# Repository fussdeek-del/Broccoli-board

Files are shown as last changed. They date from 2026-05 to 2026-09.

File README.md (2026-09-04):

# Broccoli Board


[]()
[]()
[]()
[]()
[]()

> A fully wireless 75% mechanical keyboard built from scratch custom PCB, per-key RGB, BLE 5.0, hot-swap switches, and a 3D printed case. Every component chosen, every trace routed by hand.

---

## What is it?

Broccoli Board is a custom 84-key 75% keyboard I designed completely from scratch. The PCB is designed in KiCad, the case in Fusion 360, and the firmware runs on ZMK. It's fully wireless over BLE 5.0 via the nice!nano V2, has per-key RGB LEDs reverse-mounted on the back of the PCB, and uses Kailh hot-swap sockets so I can swap switches without touching a soldering iron.

## Why i built it?
I didn't want to spend $200+ on a keyboard that still isn't fully mine. So I built one my own that belong to me.

---

## Zine

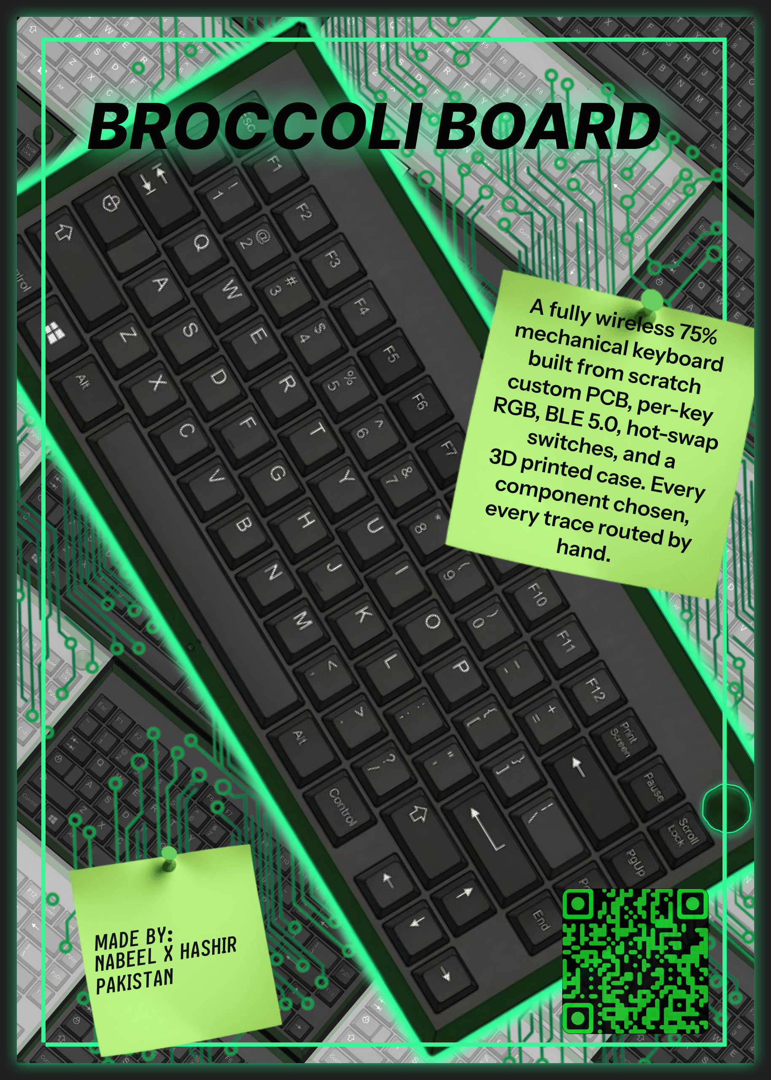
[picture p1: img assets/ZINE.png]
Zine


---

## Gallery

### CAD & Assembly
<table>
  <tr>
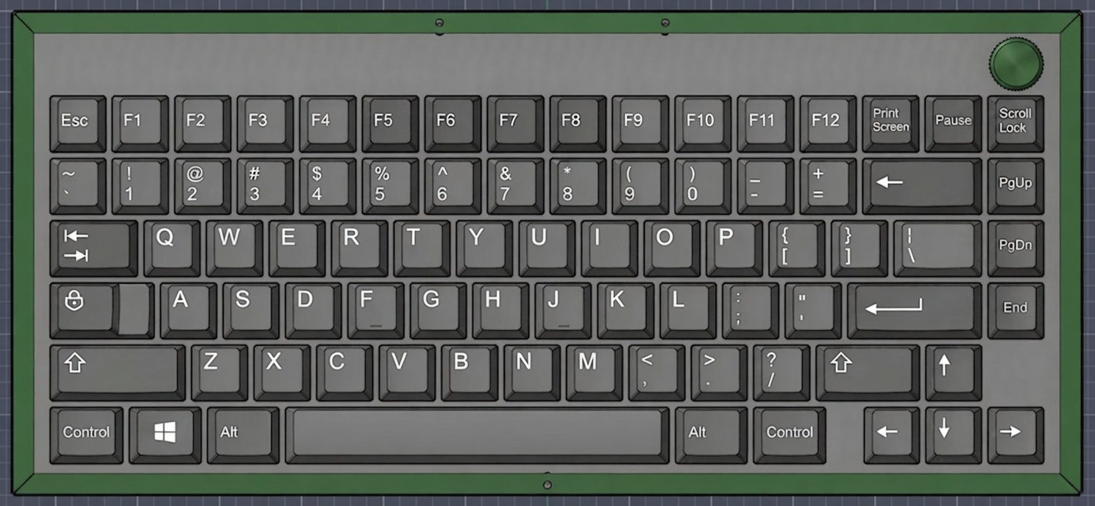
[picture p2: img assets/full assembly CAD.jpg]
    <td></td>
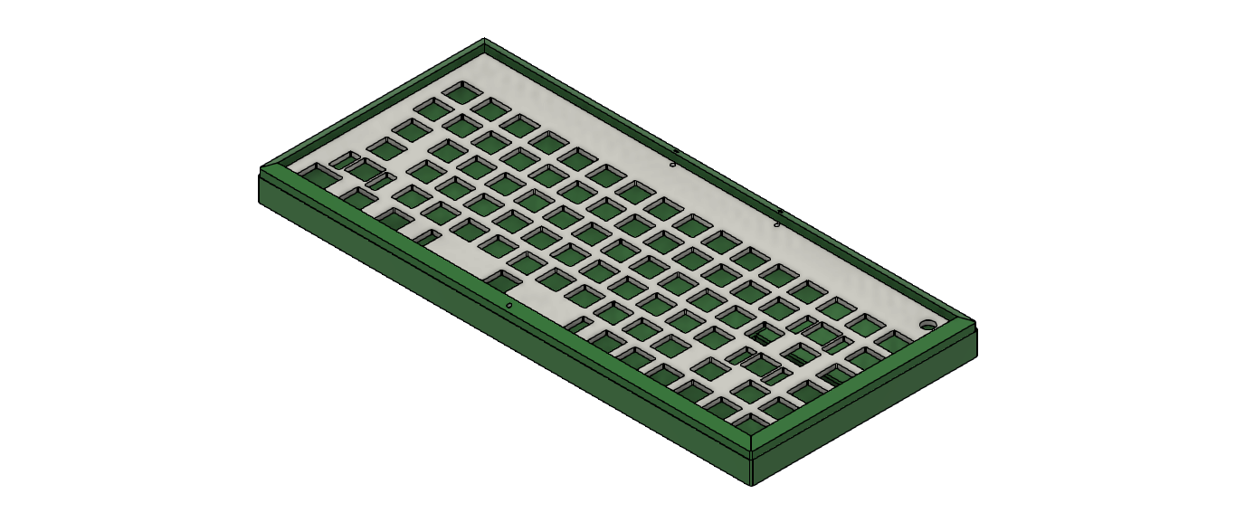
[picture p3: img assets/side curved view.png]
    <td></td>
  </tr>
</table>

### PCB
<table>
  <tr>
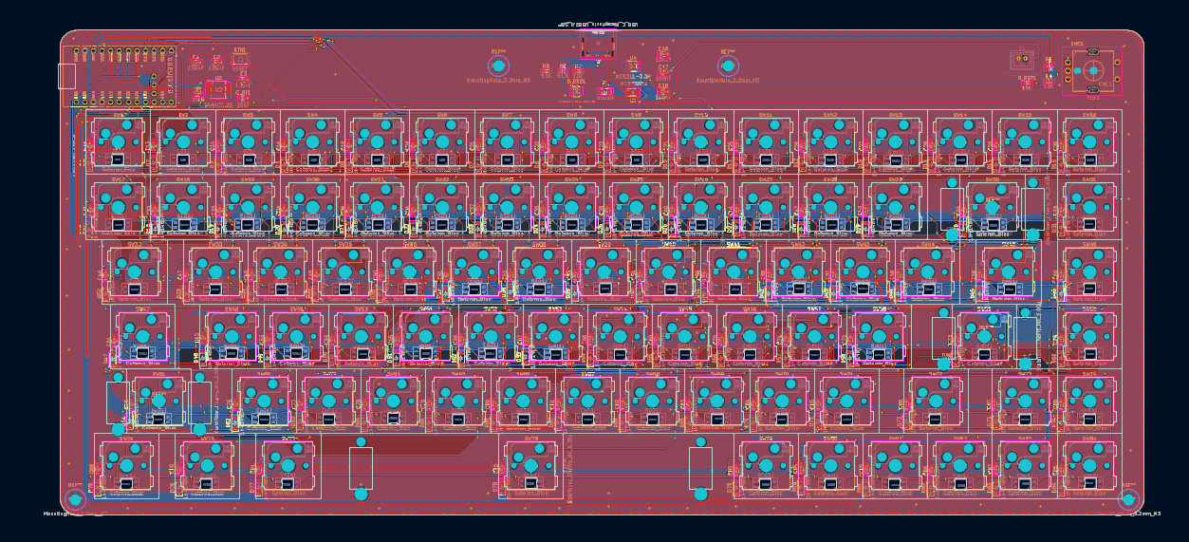
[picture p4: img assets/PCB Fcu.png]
    <td></td>
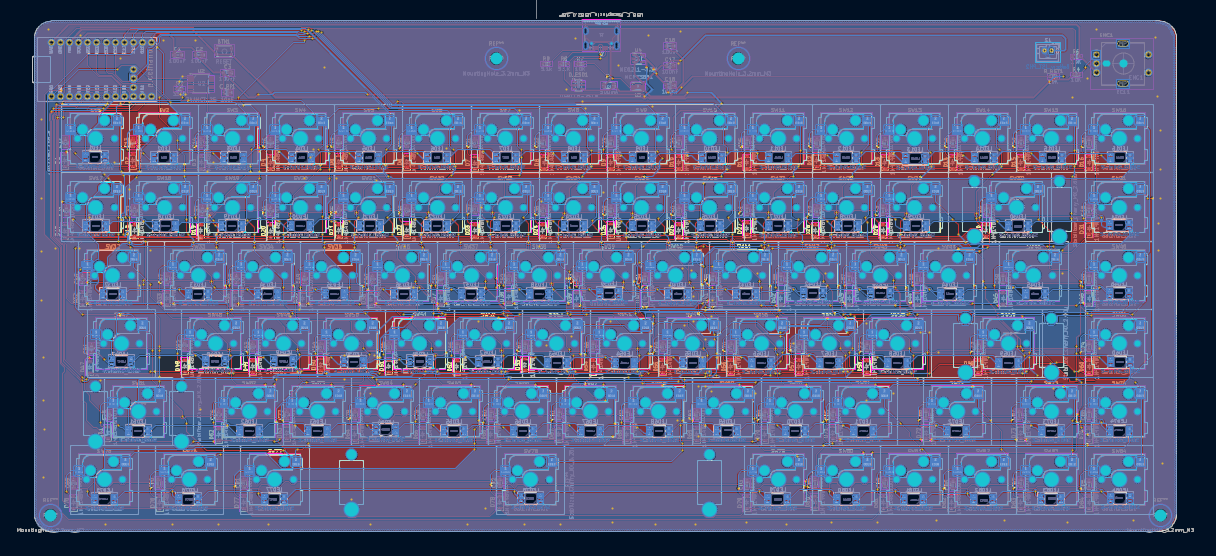
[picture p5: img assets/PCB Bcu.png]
    <td></td>
  </tr>
</table>
---

### PCB Soldered

## Features

- 84 keys, 75% layout
- Wireless BLE 5.0 via nice!nano V2 (nRF52840)
- Per-key SK6812 Mini-E RGB reverse mount on B.Cu
- Kailh hot-swap sockets no soldering to swap switches
- Rotary encoder with push switch (EC11)
- USB-C wired + wireless dual mode
- 3.7V LiPo 2000mAh with MCP73831 charger IC
- 74AHCT125 level shifter for LED data
- USBLC6-2SC6 ESD protection on USB lines
- ZMK firmware
- 2-layer PCB, KiCad 10, JLCPCB fabrication
- Custom 3D printed case tray, plate, and bezel

---

## Hardware Specs

| Component | Details |
|---|---|
| MCU | nice!nano V2 (nRF52840), socketed |
| Layout | 75%, 84 keys |
| Switches | Gateron Blue × 84, 5-pin PCB mount |
| Hotswap | Kailh CPG151101S11 × 84 |
| LEDs | SK6812 Mini-E × 84, reverse mount |
| Encoder | EC11 rotary encoder with push switch |
| Wireless | Bluetooth 5.0 BLE |
| Firmware | ZMK |
| Battery | 3.7V LiPo 2000mAh (804050), JST PH2 |
| Charger IC | MCP73831, 500mA |
| Regulator | ME6211 3.3V LDO |
| Level shifter | 74AHCT125 |
| ESD protection | USBLC6-2SC6 |
| USB connector | GCT USB4105, 16-pin USB-C |
| PCB | 2-layer, JLCPCB, KiCad 10 |
| Case | SLA resin 3D print, Fusion 360 |
| Matrix | 9 rows × 10 columns, col2row |

---

## How to Build

### Order the PCB
1. Go to [JLCPCB](https://jlcpcb.com)
2. Upload `pcb/gerbers.zip`
3. 2-layer, FR-4, 1.6mm, HASL or ENIG
4. Minimum order 5 boards

### Flash the Firmware
1. Fork the [ZMK firmware repo](https://github.com/fussdeek-del/Broccoli--board-zmk)
2. Edit keymap at `boards/shields/broccoli_board/broccoli_board.keymap`
3. Push GitHub Actions builds automatically
4. Download `.uf2` from Actions artifacts
5. Double-tap reset on nice!nano to enter bootloader
6. Drag `.uf2` onto the USB drive that appears

note: The frimware isn't completely, i will complete it once this gets approved.

### Assembly Notes
- Solder LEDs on **B.Cu** reverse mount facing down
- Solder hotswap sockets on **F.Cu**
- Solder the nice!nano v2
- Battery connects via JST PH2 to J2

## BOM

> 💰 Estimated total: **~$174 USD** — can drop to **$120–$140** buying locally.

| Component | Spec | Qty | Price | Notes | Link |
|---|---|---|---|---|---|
| Microcontroller (MCU) | nice!nano V2 nRF52840 | ×1 | $7.00 | Clone — cheaper, slightly less reliable | [Buy](https://www.aliexpress.com/item/1005006271881076.html) |
| 74AHCT125 Level Shifter | TSSOP-14 | ×1 | $2.52 | Pack of 10 — LED data 3.3V→5V | [Buy](https://www.aliexpress.com/item/1005008171122183.html) |
| MCP73831 LiPo Charger | SOT-23-5 | ×1 | $2.50 | Pack of 10 — LiPo charging IC | [Buy](https://www.aliexpress.com/item/1005007439657191.html) |
| ME6211 3.3V LDO | ME6211C33 SOT-23-5 | ×1 | $2.20 | Pack of 10 — 3.3V regulator | [Buy](https://www.aliexpress.com/item/1005007315116858.html) |
| USBLC6-2SC6 ESD Protection | SOT-23-6 | ×1 | $1.50 | Pack of 10 — USB ESD protection | [Buy](https://www.aliexpress.com/item/32807108222.html) |
| Gateron Blue Switch | G Pro Blue 5-pin | ×84 | $24.00 | Pack of 100 — 5-pin PCB mount | [Buy](https://www.aliexpress.com/item/1005006091988869.html) |
| Kailh Hotswap Socket | MX compatible | ×84 | $7.00 | Pack of 100 | [Buy](https://www.aliexpress.com/item/1005006105603269.html) |
| EC11 Rotary Encoder | 20mm with push switch | ×1 | $2.00 | Pack of 5 | [Buy](https://www.aliexpress.com/item/1005006460161288.html) |
| Reset Button | SMD tactile 3×4mm | ×1 | $1.50 | Pack of 30 | [Buy](https://www.aliexpress.com/item/4001107416458.html) |
| SK6812 Mini-E RGB LED | Reverse mount | ×84 | $13.50 | Pack of 100 — buy 100, need 84 + spares | [Buy](https://www.aliexpress.com/item/1005004249903121.html) |
| 1N4148W Matrix Diode | SOD-123 | ×84 | $1.50 | Pack of 100 — buy 100, need 84 + spares | [Buy](https://www.aliexpress.com/item/1005010728396328.html) |
| Resistor 10K | 0603 | ×10 | $1.20 | Pack of 300 | [Buy](https://www.aliexpress.com/item/1005011779883974.html) |
| Resistor 5.1K | 0603 | ×5 | $1.30 | Pack of 300 | [Buy](https://www.aliexpress.com/item/1005011779883974.html) |
| Resistor 330Ω | 0603 | ×1 | $2.00 | Pack of 500 | [Buy](https://www.aliexpress.com/item/1005005700395390.html) |
| Capacitor 100nF | 0805 | ×100 | $2.00 | Pack of 200 | [Buy](https://www.aliexpress.com/item/1005007660078779.html) |
| Capacitor 10µF | 0805 | ×1 | $2.20 | Pack of 200 | [Buy](https://www.aliexpress.com/item/1005007660078779.html) |
| USB-C Receptacle 16P | GCT USB4105 SMD | ×1 | $4.50 | Pack of 5 | [Buy](https://www.aliexpress.com/item/1005005581945089.html) |
| JST PH2 2-pin | PH2.0 2-pin connector | ×1 | $2.00 | Pack of 2 | [Buy](https://www.aliexpress.com/item/1005010615395743.html) |
| Polyfuse 500mA | Resettable fuse 1206 | ×1 | $1.70 | Pack of 10 | [Buy](https://www.aliexpress.com/item/1005005235906949.html) |
| LiPo 3.7V 2000mAh | 804050, JST PH | ×1 | $9.40 | Price for 2 | [Buy](https://www.aliexpress.com/item/1005005984841109.html) |
| Keycap Set | PBT 75% MX compatible | ×75 | $22.50 | 100+ keycaps included | [Buy](https://www.aliexpress.com/item/1005007416863215.html) |
| Rotary Knob | Aluminum 6mm D shaft 20mm | ×1 | $2.00 | 2 pieces | [Buy](https://www.aliexpress.com/item/4001091267351.html) |
| PCB Fabrication | 2-layer, FR-4, 1.6mm, HASL | ×5 boards | $22.20 | Minimum 5 pieces | [JLCPCB](https://cart.jlcpcb.com/quote) |
| 3D Print — Tray | SLA resin | ×1 | $25.30 | Local 3D printer recommended | [JLC3DP](https://jlc3dp.com/3d-printing-quote) |
| 3D Print — Top Plate | SLA resin | ×1 | $8.30 | Local 3D printer recommended | [JLC3DP](https://jlc3dp.com/3d-printing-quote) |
| 3D Print — Top Cover | SLA resin | ×1 | $2.65 | Local 3D printer recommended | [JLC3DP](https://jlc3dp.com/3d-printing-quote) |
| M3 Screws | M3 × 8mm countersunk | ×10 | $1.00 | Pack of 50 | [Buy](https://www.aliexpress.com/item/1005008810897680.html) |
| M3 Standoffs | M3 × 4mm | ×10 | $1.00 | Pack of 50 | [Buy](https://www.aliexpress.com/item/1005008810897680.html) |

---
## Schematics note
Schematics is reviewed my multiple people in fallout + AI. there was problem init that i fixed, and now it LGTM
repo is surface checked by riitam
## Credits

- [KiCad](https://www.kicad.org/) — PCB design
- [ZMK Firmware](https://zmk.dev/) — open source keyboard firmware
- [Fusion 360](https://www.autodesk.com/products/fusion-360/) — case design
- [nice!nano](https://nicekeyboards.com/nice-nano/) — nRF52840 BLE module
- [Hack Club Fallout](https://fallout.hackclub.com) — grant that made this real

Made by **Nabeel Ahmed (18) × Hashir (17)** — Punjab, Pakistan 🇵🇰 BWP

---

## License

MIT

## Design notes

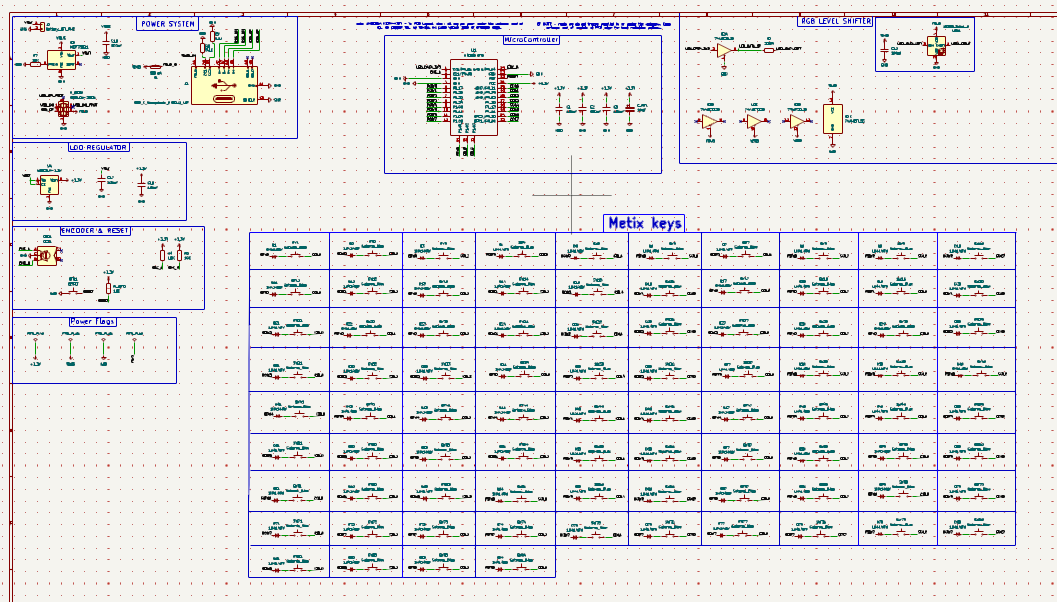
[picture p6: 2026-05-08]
img assets/schematic page1.png

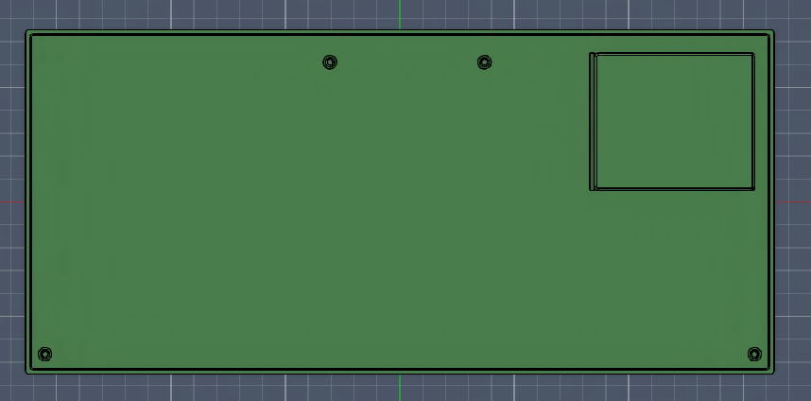
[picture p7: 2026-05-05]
img assets/Tray front.png

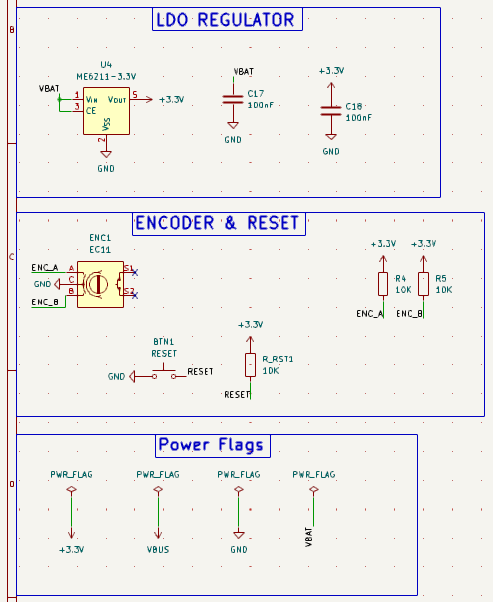
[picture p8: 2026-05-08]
img assets/small coms sch.png

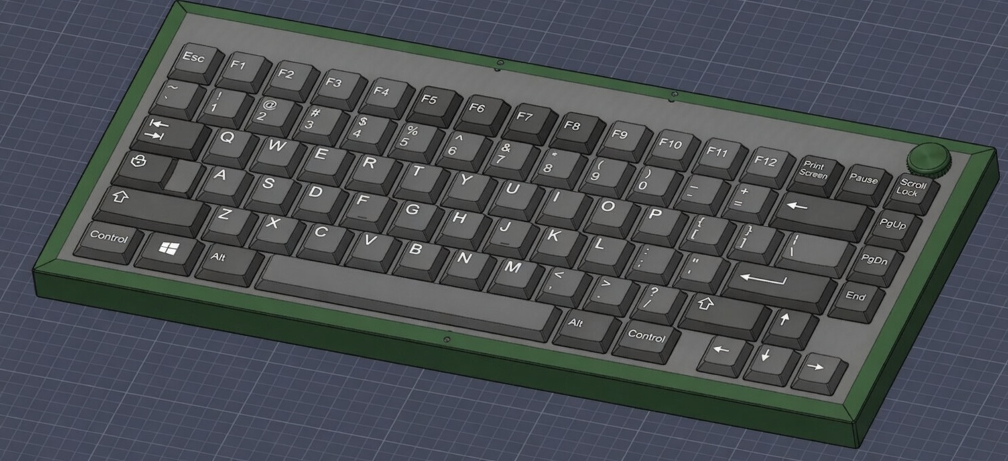
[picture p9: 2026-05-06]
img assets/CAD side look 2.jpg

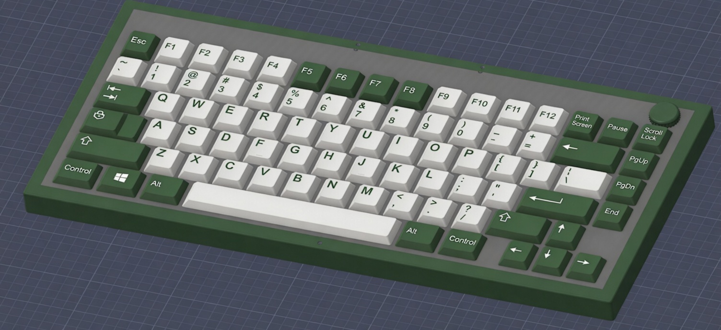
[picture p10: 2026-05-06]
img assets/AI generated final look.jpg

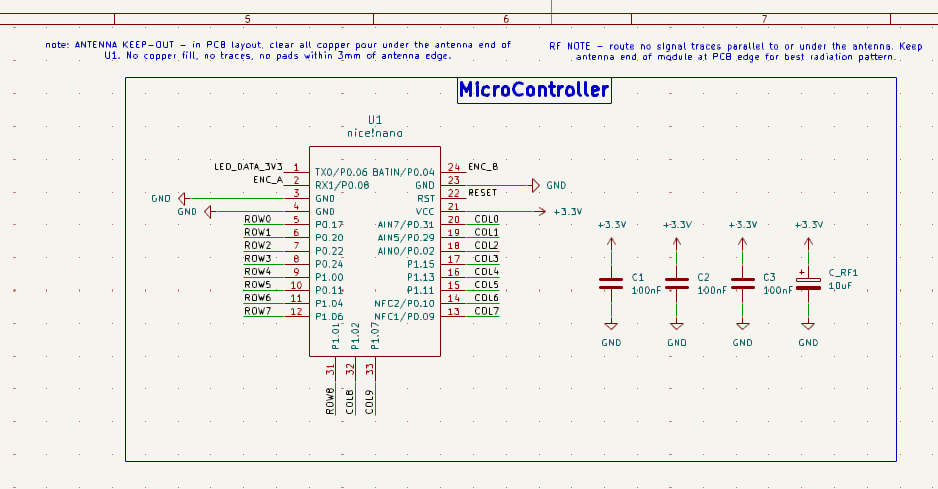
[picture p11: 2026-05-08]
img assets/Microcontroller sch.png

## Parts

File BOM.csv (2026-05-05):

Component | search name | quantity needed | link to buy | price | total | must read notes | must read notes 2.0
Microcontroller (MCU) | nice nano v2 nRF52840 | 1 | https://www.aliexpress.com/item/1005006271881076.html | $5 |  | not a orignal one | Cheaper, slightly less reliable
74AHCT125 Level Shifter | 74AHCT125 TSSOP-14 | 1 | https://www.aliexpress.com/item/1005008171122183.html | $2.52 |  | u have to buy minimum pack of ten, the price mentioned is for 10 | For LED data 3.3V→5V
MCP73831 LiPo Charger | MCP73831T-2ACI SOT-23-5 | 1 | https://www.aliexpress.com/item/1005007439657191.html | $2.5 |  | Pack of 10 price | LiPo charging IC
ME6211 3.3V LDO | ME6211C33 SOT-23-5 | 1 | https://www.aliexpress.com/item/1005007315116858.html | $2.2 |  | Pack of 10 price | 3.3V regulator
USBLC6-2SC6 ESD Protection | USBLC6-2SC6 SOT-23-6 | 1 | https://www.aliexpress.com/item/32807108222.html | $1.5 |  | Pack of 10 price | USB ESD protection
Gateron Blue Switch | Gateron G Pro Blue 5pin | 84 | https://www.aliexpress.com/item/1005006091988869.html | $24 |  | Pack of 100 price | 5-pin PCB mount
Kailh Hotswap Socket | Kailh hot swap socket MX | 84 | https://www.aliexpress.com/item/1005006105603269.html | $7 |  | Pack of 100 price | MX compatible
EC11 Rotary Encoder | EC11 rotary encoder 20mm | 1 | https://www.aliexpress.com/item/1005006460161288.html | $2 |  | pack of 5 price | With push switch
Reset Button | SMD tactile switch 3x4mm | 1 | https://www.aliexpress.com/item/4001107416458.html | $1.5 |  | pack of 30 price | Reset button
SK6812 Mini-E RGB LED | SK6812 MINI-E reverse mount | 84 | https://www.aliexpress.com/item/1005004249903121.html | $13.5 |  | pack of 100` | Buy 100, need 84 + spares
1N4148W Matrix Diode | 1N4148W SOD-123 | 84 | https://www.aliexpress.com/item/1005010728396328.html | $1.5 |  | Pack of 100 price | Buy 100, need 84 + spares
Resistor | 10K vlaue resistors 0603 | 10 | https://www.aliexpress.com/item/1005011779883974.html | $1.2 |  | pack of 300 price | u have to buy in lot
Resistor | 5.1K vlaue resistor 0603 | 5 | https://www.aliexpress.com/item/1005011779883974.html | $1.3 |  | pack of 300 price | u have to buy in lot
Resistor | 330 ohm value 0603 | 1 | https://www.aliexpress.com/item/1005005700395390.html | $2 |  | pack of 500 price | u have to buy in lot
Capacitor | 100nF value 0805 | 100 | https://www.aliexpress.com/item/1005007660078779.html | $2 |  | pack of 200 price | u have to buy in lot
Capacitor | 10uF value 0805 | 1 | https://www.aliexpress.com/item/1005007660078779.html | $2.2 |  | pack of 200 price | u have to buy in lot
USB-C Receptacle 16P | USB C 16pin SMD connector GCT USB4105 | 1 | https://www.aliexpress.com/item/1005005581945089.html | $4.5 |  | pack of 5 price | u have to buy pack of 5
JST PH2 2-pin | JST PH2.0 2pin connector | 1 | https://www.aliexpress.com/item/1005010615395743.html | $2 |  | pack of 2 price
Polyfuse 500mA | Polyfuse resettable fuse 500mA 1206 | 1 | https://www.aliexpress.com/item/1005005235906949.html | $1.7 |  | pack of 10 price
LiPo 3.7V 2000mAh | LiPo battery 804050 2000mAh 3.7V JST PH | 1 | https://www.aliexpress.com/item/1005005984841109.html | $9.4 |  | price of 2
Keycap Set | PBT keycap set 75% TKL MX compatible | 75 | https://www.aliexpress.com/item/1005007416863215.html | $22.5 |  | 100+ keycaps
Rotary Knob | encoder knob aluminum 6mm D shaft 20mm | 1 | https://www.aliexpress.com/item/4001091267351.html | $2 |  | 2 pieces
PCB Fabrication | 2-layer, HASL (with lead) | 1 | https://cart.jlcpcb.com/quote?spm=jlcpcb.Public.2006 | $22.20 |  | at least 5 pieces
3D Print - Tray | SLA resin | 1 | https://jlc3dp.com/3d-printing-quote | $25.30 |  | u should go for local 3D printer
3D Print - Top Plate | SLA resin | 1 | https://jlc3dp.com/3d-printing-quote | $8.30 |  | u should go for local 3D printer
3D Print - Top Cover | SLA resin | 1 | https://jlc3dp.com/3d-printing-quote | $2.65 |  | u should go for local 3D printer
M3 Screws | M3 x 8mm countersunk | 10 | https://www.aliexpress.com/item/1005008810897680.html | $1 |  | pack of 50
M3 Standoffs | M3 x 4mm | 10 | https://www.aliexpress.com/item/1005008810897680.html | $1 |  | pack of 50
 |  |  |  |  | $174.45 |  | if u buy components and services from locals, the price can be reduced upto $120-$140

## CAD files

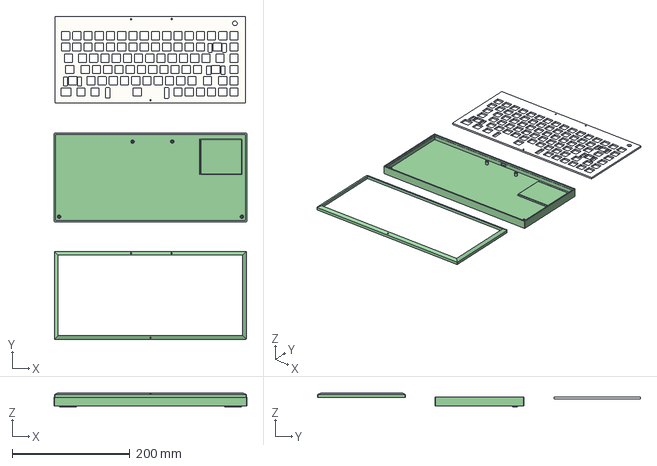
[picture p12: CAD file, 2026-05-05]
cad/keyboard full.step
327.0 x 548.0 x 24.4 mm

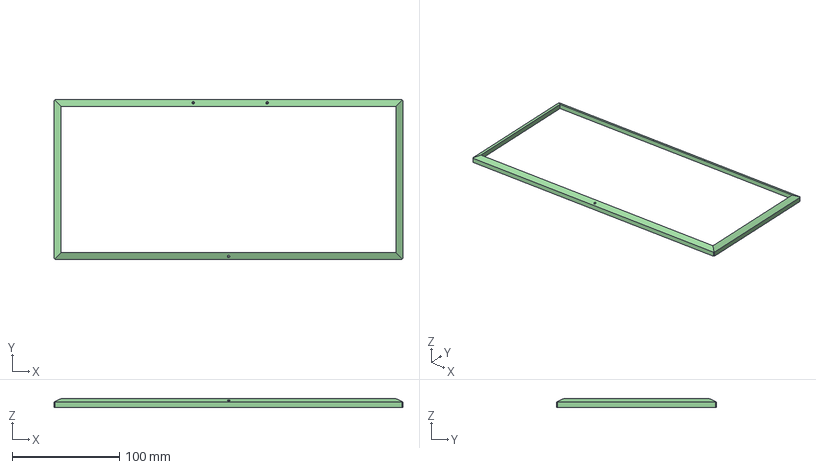
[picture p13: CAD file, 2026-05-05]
cad/Cover.step
326.0 x 149.5 x 8.00 mm

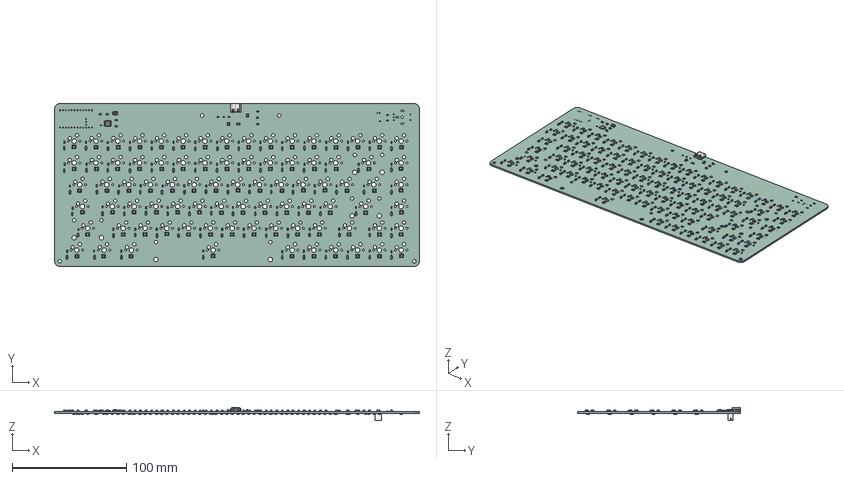
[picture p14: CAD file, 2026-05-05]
pcb/PCB.step
319.0 x 142.5 x 11.0 mm
C_0805_2012Metric x 90
D_SOD-123 x 84
R_0603_1608Metric x 8
TSSOP-14_4.4x5mm_P0.65mm
SOT-23-5
SW_Push_1P1T_NO_CK_KMR2
USB_C_Receptacle_GCT_USB4105-xx-A_16P_TopMnt_Horizontal
SOT-23-6
Fuse_1206_3216Metric
JST_PH_B2B-PH-K_1x02_P2.00mm_Vertical
Pin1 x 84
Pin2 x 84
Pin3 x 84
Pin4 x 84
Ghoost Board_PCB

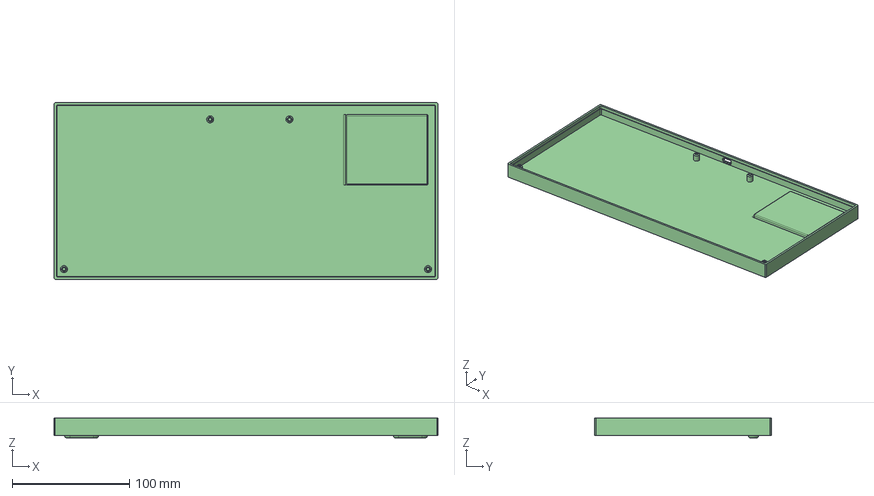
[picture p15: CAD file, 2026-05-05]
cad/tray.step
327.0 x 150.5 x 17.0 mm

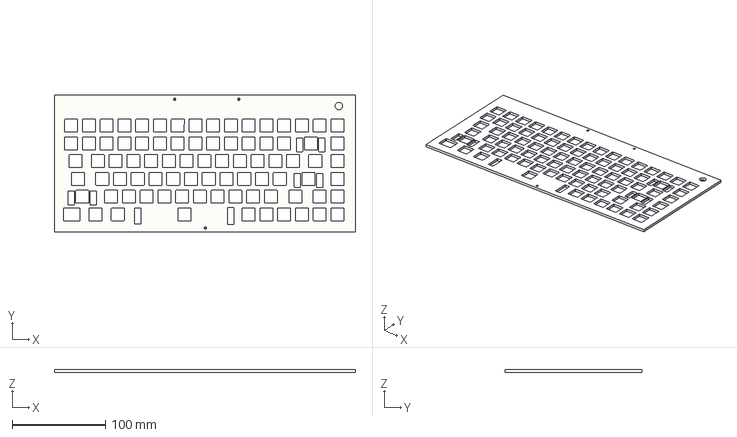
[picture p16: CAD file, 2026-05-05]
cad/plate.step
323.0 x 146.5 x 3.00 mm

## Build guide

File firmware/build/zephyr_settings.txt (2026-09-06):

# WARNING. THIS FILE IS AUTO-GENERATED. DO NOT MODIFY!
#
# This file contains build system settings derived from your modules.
#
# Modules may be set via ZEPHYR_MODULES, ZEPHYR_EXTRA_MODULES,
# and/or the west manifest file.
#
# See the Modules guide for more information.
"DTS_ROOT":"F:/OneDrive/Desktop/cloned repos/Broccoli-board/zmk-workspace/modules/hal/adi"
"DTS_ROOT":"F:/OneDrive/Desktop/cloned repos/Broccoli-board/zmk-workspace/modules/hal/atmel"
"DTS_ROOT":"F:/OneDrive/Desktop/cloned repos/Broccoli-board/zmk-workspace/modules/hal/espressif"
"DTS_ROOT":"F:/OneDrive/Desktop/cloned repos/Broccoli-board/zmk-workspace/modules/hal/gigadevice"
"DTS_ROOT":"F:/OneDrive/Desktop/cloned repos/Broccoli-board/zmk-workspace/modules/hal/microchip"
"DTS_ROOT":"F:/OneDrive/Desktop/cloned repos/Broccoli-board/zmk-workspace/modules/hal/nuvoton"
"DTS_ROOT":"F:/OneDrive/Desktop/cloned repos/Broccoli-board/zmk-workspace/modules/hal/nxp"
"DTS_ROOT":"F:/OneDrive/Desktop/cloned repos/Broccoli-board/zmk-workspace/modules/hal/stm32"
"BOARD_ROOT":"F:/OneDrive/Desktop/cloned repos/Broccoli-board/zmk-workspace/zmk.git/app/module"
"DTS_ROOT":"F:/OneDrive/Desktop/cloned repos/Broccoli-board/zmk-workspace/zmk.git/app/module"
"MODULE_EXT_ROOT":"F:/OneDrive/Desktop/cloned repos/Broccoli-board/zmk-workspace/zmk.git/app/keymap-module"

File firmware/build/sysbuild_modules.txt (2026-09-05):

"mcuboot":"F:/OneDrive/Desktop/cloned repos/Broccoli-board/zmk-workspace/bootloader/mcuboot":"F:/OneDrive/Desktop/cloned repos/Broccoli-board/zmk-workspace/bootloader/mcuboot/boot/zephyr/sysbuild"

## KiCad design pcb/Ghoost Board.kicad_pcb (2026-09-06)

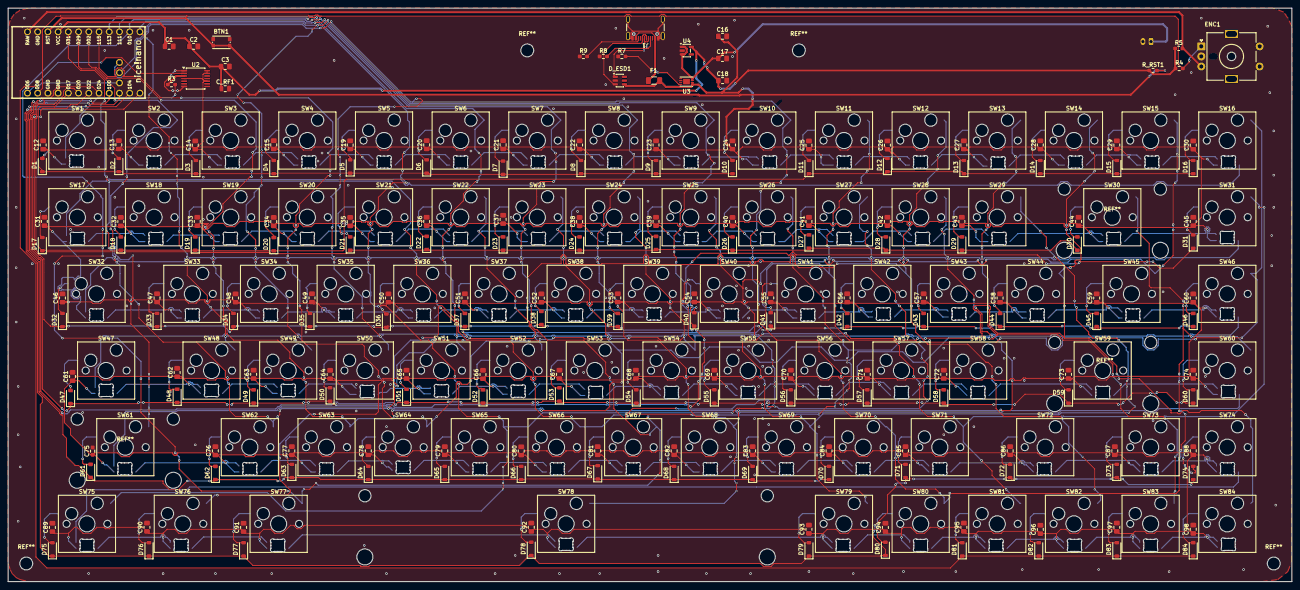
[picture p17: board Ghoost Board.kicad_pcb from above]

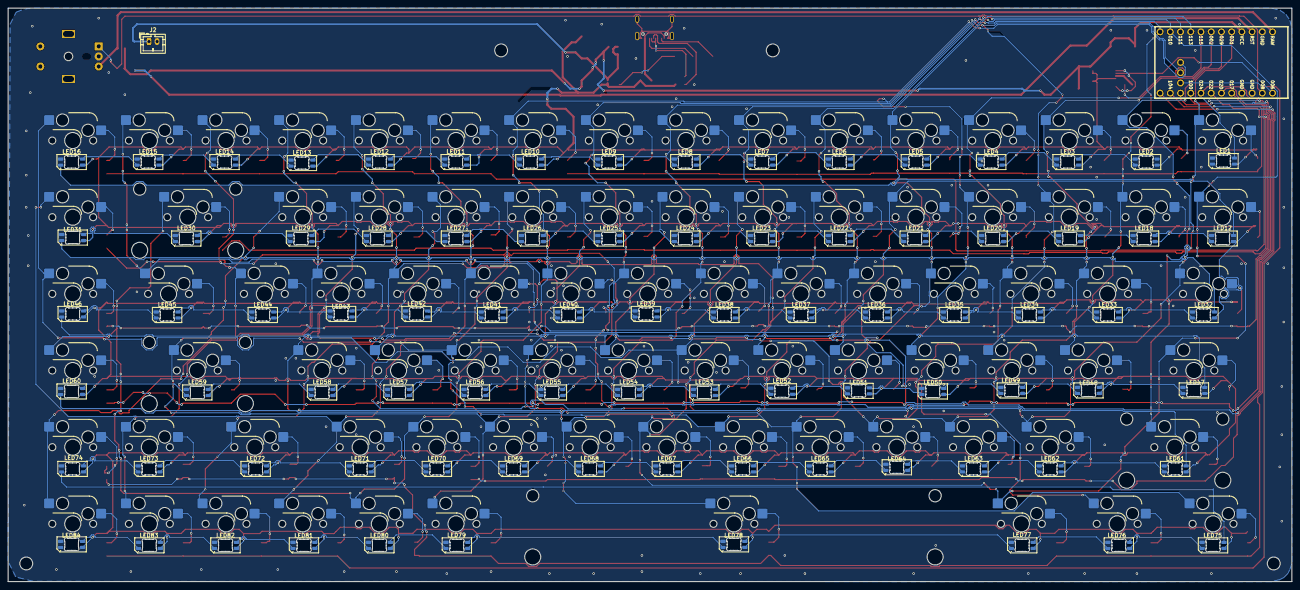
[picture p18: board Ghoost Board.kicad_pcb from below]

Board: 2 copper layers, 319.0 x 142.5 mm, 360 parts (85 on the bottom side), 201 nets.

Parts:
BTN1: RESET; SW_Push_1P1T_NO_CK_KMR2
C1, C2, C3, C17, C18: 100nF; C_0805_2012Metric_Pad1.18x1.45mm_HandSolder
C12, C13, C14, C15, C16, C19, C20, C21, C22, C23, C24, C25, C26, C27, C28, C29, C30, C31, C32, C33, C34, C35, C36, C37, C38, C39, C40, C41, C42, C43, C44, C45, C46, C47, C48, C49, C50, C51, C52, C53, C54, C55, C56, C57, C58, C59, C60, C61, C62, C63, C64, C65, C66, C67, C68, C69, C70, C71, C72, C73, C74, C76, C77, C78, C79, C80, C81, C82, C83, C84, C85, C86, C87, C88, C89, C90, C91, C92, C93, C94, C95, C96, C97, C98: 100nf; C_0805_2012Metric_Pad1.18x1.45mm_HandSolder
C75: 100nf; R_0603_1608Metric_Pad0.98x0.95mm_HandSolder
C_RF1: 10uF; C_0805_2012Metric
D1, D2, D3, D4, D5, D6, D7, D8, D9, D10, D11, D12, D13, D14, D15, D16, D17, D18, D19, D20, D21, D22, D23, D24, D25, D26, D27, D28, D29, D30, D31, D32, D33, D34, D35, D36, D37, D38, D39, D40, D41, D42, D43, D44, D45, D46, D47, D48, D49, D50, D51, D52, D53, D54, D55, D56, D57, D58, D59, D60, D61, D62, D63, D64, D65, D66, D67, D68, D69, D70, D71, D72, D73, D74, D75, D76, D77, D78, D79, D80, D81, D82, D83, D84: 1N4148W; D_SOD-123
D_ESD1: USBLC6-2SC6; SOT-23-6
ENC1: EC11; RotaryEncoder_Alps_EC11E-Switch_Vertical_H20mm_MountingHoles
F1: 500mA; Fuse_1206_3216Metric
J1: USB_C_Receptacle_USB2.0_16P; USB_C_Receptacle_GCT_USB4105-xx-A_16P_TopMnt_Horizontal
J2: Battery_JST_PH2; JST_PH_B2B-PH-K_1x02_P2.00mm_Vertical
LED1, LED2, LED3, LED4, LED5, LED6, LED7, LED8, LED9, LED10, LED11, LED12, LED13, LED14, LED15, LED16, LED17, LED18, LED19, LED20, LED21, LED22, LED23, LED24, LED25, LED26, LED27, LED28, LED29, LED30, LED31, LED32, LED33, LED34, LED35, LED36, LED37, LED38, LED39, LED40, LED41, LED42, LED43, LED44, LED45, LED46, LED47, LED48, LED49, LED50, LED51, LED52, LED53, LED54, LED55, LED56, LED57, LED58, LED59, LED60, LED61, LED62, LED63, LED64, LED65, LED66, LED67, LED68, LED69, LED70, LED71, LED72, LED73, LED74, LED75, LED76, LED77, LED78, LED79, LED80, LED81, LED82, LED83, LED84: SK6812Mini-E; LED_SK6812MINI-E_3.2x2.8mm_P1.5mm_ReverseMount
R3: 330R; R_0603_1608Metric_Pad0.98x0.95mm_HandSolder
R4, R5, R7: 10K; R_0603_1608Metric_Pad0.98x0.95mm_HandSolder
R8: 5.1K; R_0603_1608Metric_Pad0.98x0.95mm_HandSolder
R9: 5.1k; R_0603_1608Metric_Pad0.98x0.95mm_HandSolder
R_RST1: 10K; R_0603_1608Metric_Pad0.98x0.95mm_HandSolder
SW1, SW2, SW3, SW4, SW5, SW6, SW7, SW8, SW9, SW10, SW11, SW12, SW13, SW14, SW15, SW16, SW17, SW18, SW19, SW20, SW21, SW22, SW23, SW24, SW25, SW26, SW27, SW28, SW29, SW30, SW31, SW32, SW33, SW34, SW35, SW36, SW37, SW38, SW39, SW40, SW41, SW42, SW43, SW44, SW45, SW46, SW47, SW48, SW49, SW50, SW51, SW52, SW53, SW54, SW55, SW56, SW57, SW58, SW59, SW60, SW61, SW62, SW63, SW64, SW65, SW66, SW67, SW68, SW69, SW70, SW71, SW72, SW73, SW74, SW75, SW76, SW77, SW78, SW79, SW80, SW81, SW82, SW83, SW84: Gateron_Blue; SW_Hotswap_Kailh_MX_1.00u
U1: nice!nano; nice_nano
U2: 74AHCT125; TSSOP-14_4.4x5mm_P0.65mm
U3: MCP73831; DFN-8-1EP_3x2mm_P0.5mm_EP1.7x1.4mm
U4: ME6211-3.3V; SOT-23-5

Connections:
+3.3V: C1.1, C2.1, C3.1, C18.1, C_RF1.1, R4.1, R5.1, R_RST1.1, U1.21 (VCC), U4.5 (V_{OUT})
/COL0: SW1.2, SW11.2, SW21.2, SW31.2, SW41.2, SW51.2, SW61.2, SW71.2, SW81.2, U1.20 (AIN7/P0.31)
/COL1: SW2.2, SW12.2, SW22.2, SW32.2, SW42.2, SW52.2, SW62.2, SW72.2, SW82.2, U1.19 (AIN5/P0.29)
/COL2: SW3.2, SW13.2, SW23.2, SW33.2, SW43.2, SW53.2, SW63.2, SW73.2, SW83.2, U1.18 (AIN0/P0.02)
/COL3: SW4.2, SW14.2, SW24.2, SW34.2, SW44.2, SW54.2, SW64.2, SW74.2, SW84.2, U1.17 (P1.15)
/COL4: SW5.2, SW15.2, SW25.2, SW35.2, SW45.2, SW55.2, SW65.2, SW75.2, U1.16 (P1.13)
/COL5: SW6.2, SW16.2, SW26.2, SW36.2, SW46.2, SW56.2, SW66.2, SW76.2, U1.15 (P1.11)
/COL6: SW7.2, SW17.2, SW27.2, SW37.2, SW47.2, SW57.2, SW67.2, SW77.2, U1.14 (NFC2/P0.10)
/COL7: SW8.2, SW18.2, SW28.2, SW38.2, SW48.2, SW58.2, SW68.2, SW78.2, U1.13 (NFC1/P0.09)
/COL8: SW9.2, SW19.2, SW29.2, SW39.2, SW49.2, SW59.2, SW69.2, SW79.2, U1.32 (P1.02)
/COL9: SW10.2, SW20.2, SW30.2, SW40.2, SW50.2, SW60.2, SW70.2, SW80.2, U1.33 (P1.07)
/ENC_A: ENC1.A, R4.2, U1.2 (RX1/P0.08)
/ENC_B: ENC1.B, R5.2, U1.24 (BATIN/P0.04)
/LED sheets/LED2_DOUT: LED2.1 (DOUT), LED3.3 (DIN)
/LED sheets/LED3_DOUT: LED3.1 (DOUT), LED4.3 (DIN)
/LED sheets/LED4_DOUT: LED4.1 (DOUT), LED5.3 (DIN)
/LED sheets/LED5_DOUT: LED5.1 (DOUT), LED6.3 (DIN)
/LED sheets/LED6_DOUT: LED6.1 (DOUT), LED7.3 (DIN)
/LED sheets/LED7_DOUT: LED7.1 (DOUT), LED8.3 (DIN)
/LED sheets/LED8_DOUT: LED8.1 (DOUT), LED9.3 (DIN)
/LED sheets/LED9_DOUT: LED9.1 (DOUT), LED10.3 (DIN)
/LED sheets/LED10_DOUT: LED10.1 (DOUT), LED11.3 (DIN)
/LED sheets/LED11_DOUT: LED11.1 (DOUT), LED12.3 (DIN)
/LED sheets/LED12_DOUT: LED12.1 (DOUT), LED13.3 (DIN)
/LED sheets/LED13_DOUT: LED13.1 (DOUT), LED14.3 (DIN)
/LED sheets/LED14_DOUT: LED14.1 (DOUT), LED15.3 (DIN)
/LED sheets/LED15_DOUT: LED15.1 (DOUT), LED16.3 (DIN)
/LED sheets/LED16_DOUT: LED16.1 (DOUT), LED17.3 (DIN)
/LED sheets/LED17_DOUT: LED17.1 (DOUT), LED18.3 (DIN)
/LED sheets/LED18_DOUT: LED18.1 (DOUT), LED19.3 (DIN)
/LED sheets/LED19_DOUT: LED19.1 (DOUT), LED20.3 (DIN)
/LED sheets/LED20_DOUT: LED20.1 (DOUT), LED21.3 (DIN)
/LED sheets/LED21_DOUT: LED21.1 (DOUT), LED22.3 (DIN)
/LED sheets/LED22_DOUT: LED22.1 (DOUT), LED23.3 (DIN)
/LED sheets/LED23_DOUT: LED23.1 (DOUT), LED24.3 (DIN)
/LED sheets/LED24_DOUT: LED24.1 (DOUT), LED25.3 (DIN)
/LED sheets/LED25_DOUT: LED25.1 (DOUT), LED26.3 (DIN)
/LED sheets/LED26_DOUT: LED26.1 (DOUT), LED27.3 (DIN)
/LED sheets/LED27_DOUT: LED27.1 (DOUT), LED28.3 (DIN)
/LED sheets/LED28_DOUT: LED28.1 (DOUT), LED29.3 (DIN)
/LED sheets/LED29_DOUT: LED29.1 (DOUT), LED30.3 (DIN)
/LED sheets/LED30_DOUT: LED30.1 (DOUT), LED31.3 (DIN)
/LED sheets/LED31_DOUT: LED31.1 (DOUT), LED32.3 (DIN)
/LED sheets/LED32_DOUT: LED32.1 (DOUT), LED33.3 (DIN)
/LED sheets/LED33_DOUT: LED33.1 (DOUT), LED34.3 (DIN)
/LED sheets/LED34_DOUT: LED34.1 (DOUT), LED35.3 (DIN)
/LED sheets/LED35_DOUT: LED35.1 (DOUT), LED36.3 (DIN)
/LED sheets/LED36_DOUT: LED36.1 (DOUT), LED37.3 (DIN)
/LED sheets/LED37_DOUT: LED37.1 (DOUT), LED38.3 (DIN)
/LED sheets/LED38_DOUT: LED38.1 (DOUT), LED39.3 (DIN)
/LED sheets/LED39_DOUT: LED39.1 (DOUT), LED40.3 (DIN)
/LED sheets/LED40_DOUT: LED40.1 (DOUT), LED41.3 (DIN)
/LED sheets/LED41_DOUT: LED41.1 (DOUT), LED42.3 (DIN)
/LED sheets/LED42_DOUT: LED42.1 (DOUT), LED43.3 (DIN)
/LED sheets/LED43_DOUT: LED43.1 (DOUT), LED44.3 (DIN)
/LED sheets/LED44_DOUT: LED44.1 (DOUT), LED45.3 (DIN)
/LED sheets/LED45_DOUT: LED45.1 (DOUT), LED46.3 (DIN)
/LED sheets/LED46_DOUT: LED46.1 (DOUT), LED47.3 (DIN)
/LED sheets/LED47_DOUT: LED47.1 (DOUT), LED48.3 (DIN)
/LED sheets/LED48_DOUT: LED48.1 (DOUT), LED49.3 (DIN)
/LED sheets/LED49_DOUT: LED49.1 (DOUT), LED50.3 (DIN)
/LED sheets/LED50_DOUT: LED50.1 (DOUT), LED51.3 (DIN)
/LED sheets/LED51_DOUT: LED51.1 (DOUT), LED52.3 (DIN)
/LED sheets/LED52_DOUT: LED52.1 (DOUT), LED53.3 (DIN)
/LED sheets/LED53_DOUT: LED53.1 (DOUT), LED54.3 (DIN)
/LED sheets/LED54_DOUT: LED54.1 (DOUT), LED55.3 (DIN)
/LED sheets/LED55_DOUT: LED55.1 (DOUT), LED56.3 (DIN)
/LED sheets/LED56_DOUT: LED56.1 (DOUT), LED57.3 (DIN)
/LED sheets/LED57_DOUT: LED57.1 (DOUT), LED58.3 (DIN)
/LED sheets/LED58_DOUT: LED58.1 (DOUT), LED59.3 (DIN)
/LED sheets/LED59_DOUT: LED59.1 (DOUT), LED60.3 (DIN)
/LED sheets/LED60_DOUT: LED60.1 (DOUT), LED61.3 (DIN)
/LED sheets/LED61_DOUT: LED61.1 (DOUT), LED62.3 (DIN)
/LED sheets/LED62_DOUT: LED62.1 (DOUT), LED63.3 (DIN)
/LED sheets/LED63_DOUT: LED63.1 (DOUT), LED64.3 (DIN)
/LED sheets/LED64_DOUT: LED64.1 (DOUT), LED65.3 (DIN)
/LED sheets/LED65_DOUT: LED65.1 (DOUT), LED66.3 (DIN)
/LED sheets/LED66_DOUT: LED66.1 (DOUT), LED67.3 (DIN)
/LED sheets/LED67_DOUT: LED67.1 (DOUT), LED68.3 (DIN)
/LED sheets/LED68_DOUT: LED68.1 (DOUT), LED69.3 (DIN)
/LED sheets/LED69_DOUT: LED69.1 (DOUT), LED70.3 (DIN)
/LED sheets/LED70_DOUT: LED70.1 (DOUT), LED71.3 (DIN)
/LED sheets/LED71_DOUT: LED71.1 (DOUT), LED72.3 (DIN)
/LED sheets/LED72_DOUT: LED72.1 (DOUT), LED73.3 (DIN)
/LED sheets/LED73_DOUT: LED73.1 (DOUT), LED74.3 (DIN)
/LED sheets/LED74_DOUT: LED74.1 (DOUT), LED75.3 (DIN)
/LED sheets/LED75_DOUT: LED75.1 (DOUT), LED76.3 (DIN)
/LED sheets/LED76_DOUT: LED76.1 (DOUT), LED77.3 (DIN)
/LED sheets/LED77_DOUT: LED77.1 (DOUT), LED78.3 (DIN)
/LED sheets/LED78_DOUT: LED78.1 (DOUT), LED79.3 (DIN)
/LED sheets/LED79_DOUT: LED79.1 (DOUT), LED80.3 (DIN)
/LED sheets/LED80_DOUT: LED80.1 (DOUT), LED81.3 (DIN)
/LED sheets/LED81_DOUT: LED81.1 (DOUT), LED82.3 (DIN)
/LED sheets/LED82_DOUT: LED82.1 (DOUT), LED83.3 (DIN)
/LED sheets/LED83_DOUT: LED83.1 (DOUT), LED84.3 (DIN)
/LED_DATA_3V3: U1.1 (TX0/P0.06), U2.2
/LED_DATA_5V: R3.1, U2.3
/LED_DATA_OUT: LED1.3 (DIN), R3.2
/RESET: BTN1.2, R_RST1.2, U1.22 (RST)
/ROW0: D1.1 (K), D2.1 (K), D3.1 (K), D4.1 (K), D5.1 (K), D6.1 (K), D7.1 (K), D8.1 (K), D9.1 (K), D10.1 (K), U1.5 (P0.17)
/ROW1: D11.1 (K), D12.1 (K), D13.1 (K), D14.1 (K), D15.1 (K), D16.1 (K), D17.1 (K), D18.1 (K), D19.1 (K), D20.1 (K), U1.6 (P0.20)
/ROW2: D21.1 (K), D22.1 (K), D23.1 (K), D24.1 (K), D25.1 (K), D26.1 (K), D27.1 (K), D28.1 (K), D29.1 (K), D30.1 (K), U1.7 (P0.22)
/ROW3: D31.1 (K), D32.1 (K), D33.1 (K), D34.1 (K), D35.1 (K), D36.1 (K), D37.1 (K), D38.1 (K), D39.1 (K), D40.1 (K), U1.8 (P0.24)
/ROW4: D41.1 (K), D42.1 (K), D43.1 (K), D44.1 (K), D45.1 (K), D46.1 (K), D47.1 (K), D48.1 (K), D49.1 (K), D50.1 (K), U1.9 (P1.00)
/ROW5: D51.1 (K), D52.1 (K), D53.1 (K), D54.1 (K), D55.1 (K), D56.1 (K), D57.1 (K), D58.1 (K), D59.1 (K), D60.1 (K), U1.10 (P0.11)
/ROW6: D61.1 (K), D62.1 (K), D63.1 (K), D64.1 (K), D65.1 (K), D66.1 (K), D67.1 (K), D68.1 (K), D69.1 (K), D70.1 (K), U1.11 (P1.04)
/ROW7: D71.1 (K), D72.1 (K), D73.1 (K), D74.1 (K), D75.1 (K), D76.1 (K), D77.1 (K), D78.1 (K), D79.1 (K), D80.1 (K), U1.12 (P1.06)
/ROW8: D81.1 (K), D82.1 (K), D83.1 (K), D84.1 (K), U1.31 (P1.01)
/USB_DN: D_ESD1.1 (I/O1), J1.A7 (D-), J1.B7 (D-)
/USB_DP: D_ESD1.3 (I/O2), J1.A6 (D+), J1.B6 (D+)
/VBAT: C17.1, J2.1, U3.3 (V_{BAT}), U3.4 (V_{BAT}), U4.1 (V_{IN}), U4.3 (CE)
/VBUS_IN: F1.1, J1.A4 (VBUS), J1.A9 (VBUS), J1.B4 (VBUS), J1.B9 (VBUS)
GND: BTN1.1, C1.2, C2.2, C3.2, C12.2, C13.2, C14.2, C15.2, C16.2, C17.2, C18.2, C19.2, C20.2, C21.2, C22.2, C23.2, C24.2, C25.2, C26.2, C27.2, C28.2, C29.2, C30.2, C31.2, C32.2, C33.2, C34.2, C35.2, C36.2, C37.2, C38.2, C39.2, C40.2, C41.2, C42.2, C43.2, C44.2, C45.2, C46.2, C47.2, C48.2, C49.2, C50.2, C51.2, C52.2, C53.2, C54.2, C55.2, C56.2, C57.2, C58.2, C59.2, C60.2, C61.2, C62.2, C63.2, C64.2, C65.2, C66.2, C67.2, C68.2, C69.2, C70.2, C71.2, C72.2, C73.2, C74.2, C75.2, C76.2, C77.2, C78.2, C79.2, C80.2, C81.2, C82.2, C83.2, C84.2, C85.2, C86.2, C87.2, C88.2, C89.2, C90.2, C91.2, C92.2, C93.2, C94.2, C95.2, C96.2, C97.2, C98.2, C_RF1.2, D_ESD1.2 (GND), ENC1.C, J1.A1 (GND), J1.A12 (GND), J1.B1 (GND), J1.B12 (GND), J1.SH (SHIELD), J2.2, LED1.2 (VSS), LED2.2 (VSS), LED3.2 (VSS), LED4.2 (VSS), LED5.2 (VSS), LED6.2 (VSS), LED7.2 (VSS), LED8.2 (VSS), LED9.2 (VSS), LED10.2 (VSS), LED11.2 (VSS), LED12.2 (VSS), LED13.2 (VSS), LED14.2 (VSS), LED15.2 (VSS), LED16.2 (VSS), LED17.2 (VSS), LED18.2 (VSS), LED19.2 (VSS), LED20.2 (VSS), LED21.2 (VSS), LED22.2 (VSS), LED23.2 (VSS), LED24.2 (VSS), LED25.2 (VSS), LED26.2 (VSS), LED27.2 (VSS), LED28.2 (VSS), LED29.2 (VSS), LED30.2 (VSS), LED31.2 (VSS), LED32.2 (VSS), LED33.2 (VSS), LED34.2 (VSS), LED35.2 (VSS), LED36.2 (VSS), LED37.2 (VSS), LED38.2 (VSS), LED39.2 (VSS), LED40.2 (VSS), LED41.2 (VSS), LED42.2 (VSS), LED43.2 (VSS), LED44.2 (VSS), LED45.2 (VSS), LED46.2 (VSS), LED47.2 (VSS), LED48.2 (VSS), LED49.2 (VSS), LED50.2 (VSS), LED51.2 (VSS), LED52.2 (VSS), LED53.2 (VSS), LED54.2 (VSS), LED55.2 (VSS), LED56.2 (VSS), LED57.2 (VSS), LED58.2 (VSS), LED59.2 (VSS), LED60.2 (VSS), LED61.2 (VSS), LED62.2 (VSS), LED63.2 (VSS), LED64.2 (VSS), LED65.2 (VSS), LED66.2 (VSS), LED67.2 (VSS), LED68.2 (VSS), LED69.2 (VSS), LED70.2 (VSS), LED71.2 (VSS), LED72.2 (VSS), LED73.2 (VSS), LED74.2 (VSS), LED75.2 (VSS), LED76.2 (VSS), LED77.2 (VSS), LED78.2 (VSS), LED79.2 (VSS), LED80.2 (VSS), LED81.2 (VSS), LED82.2 (VSS), LED83.2 (VSS), LED84.2 (VSS), R7.1, R8.1, R9.1, U1.3 (GND), U1.4 (GND), U1.23 (GND), U2.1, U2.7 (GND), U3.6 (V_{SS}), U4.2 (V_{SS})
unnamed: D1.2 (A), SW1.1
unnamed: D2.2 (A), SW2.1
unnamed: D3.2 (A), SW3.1
unnamed: D4.2 (A), SW4.1
unnamed: D5.2 (A), SW5.1
unnamed: D6.2 (A), SW6.1
unnamed: D7.2 (A), SW7.1
unnamed: D8.2 (A), SW8.1
unnamed: D9.2 (A), SW9.1
unnamed: D10.2 (A), SW10.1
unnamed: D11.2 (A), SW11.1
unnamed: D12.2 (A), SW12.1
unnamed: D13.2 (A), SW13.1
unnamed: D14.2 (A), SW14.1
unnamed: D15.2 (A), SW15.1
unnamed: D16.2 (A), SW16.1
unnamed: D17.2 (A), SW17.1
unnamed: D18.2 (A), SW18.1
unnamed: D19.2 (A), SW19.1
unnamed: D20.2 (A), SW20.1
unnamed: D21.2 (A), SW21.1
unnamed: D22.2 (A), SW22.1
unnamed: D23.2 (A), SW23.1
unnamed: D24.2 (A), SW24.1
unnamed: D25.2 (A), SW25.1
unnamed: D26.2 (A), SW26.1
unnamed: D27.2 (A), SW27.1
unnamed: D28.2 (A), SW28.1
unnamed: D29.2 (A), SW29.1
unnamed: D30.2 (A), SW30.1
unnamed: D31.2 (A), SW31.1
unnamed: D32.2 (A), SW32.1
unnamed: D33.2 (A), SW33.1
unnamed: D34.2 (A), SW34.1
unnamed: D35.2 (A), SW35.1
unnamed: D36.2 (A), SW36.1
unnamed: D37.2 (A), SW37.1
unnamed: D38.2 (A), SW38.1
unnamed: D39.2 (A), SW39.1
unnamed: D40.2 (A), SW40.1
unnamed: D41.2 (A), SW41.1
unnamed: D42.2 (A), SW42.1
unnamed: D43.2 (A), SW43.1
unnamed: D44.2 (A), SW44.1
unnamed: D45.2 (A), SW45.1
unnamed: D46.2 (A), SW46.1
unnamed: D47.2 (A), SW47.1
unnamed: D48.2 (A), SW48.1
unnamed: D49.2 (A), SW49.1
unnamed: D50.2 (A), SW50.1
unnamed: D51.2 (A), SW51.1
unnamed: D52.2 (A), SW52.1
unnamed: D53.2 (A), SW53.1
unnamed: D54.2 (A), SW54.1
unnamed: D55.2 (A), SW55.1
unnamed: D56.2 (A), SW56.1
unnamed: D57.2 (A), SW57.1
unnamed: D58.2 (A), SW58.1
unnamed: D59.2 (A), SW59.1
unnamed: D60.2 (A), SW60.1
unnamed: D61.2 (A), SW61.1
unnamed: D62.2 (A), SW62.1
unnamed: D63.2 (A), SW63.1
unnamed: D64.2 (A), SW64.1
unnamed: D65.2 (A), SW65.1
unnamed: D66.2 (A), SW66.1
unnamed: D67.2 (A), SW67.1
unnamed: D68.2 (A), SW68.1
unnamed: D69.2 (A), SW69.1
unnamed: D70.2 (A), SW70.1
unnamed: D71.2 (A), SW71.1
unnamed: D72.2 (A), SW72.1
unnamed: D73.2 (A), SW73.1
unnamed: D74.2 (A), SW74.1
unnamed: D75.2 (A), SW75.1
unnamed: D76.2 (A), SW76.1
unnamed: D77.2 (A), SW77.1
unnamed: D78.2 (A), SW78.1
unnamed: D79.2 (A), SW79.1
unnamed: D80.2 (A), SW80.1
unnamed: D81.2 (A), SW81.1
unnamed: D82.2 (A), SW82.1
unnamed: D83.2 (A), SW83.1
unnamed: D84.2 (A), SW84.1
unnamed: J1.A5 (CC1), R8.2
unnamed: J1.B5 (CC2), R9.2
unnamed: R7.2, U3.8 (PROG)
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

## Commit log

2026-05-05 Add all project files
    [2nd page.kicad_sch, Broccoli board BOM.csv, Cover.step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]
2026-05-07 Revise README for Broccoli Board project
    Updated README.md for clarity and detail on the Broccoli Board project, including hardware specs, build instructions, and repo structure.
2026-05-07 Fix image filename for full assembly demo
2026-05-07 Update image format for PCB F.cu in README
2026-05-07 alomost done
    [2nd page.kicad_sch]
2026-05-07 Enhance BOM section with detailed component info
    Updated the Bill of Materials (BOM) section with detailed component specifications, quantities, prices, and purchase links.
2026-05-07 cad file added
2026-05-07 Update README with schematics note
    Added a note about schematics review and fixed issues.
2026-09-06 Fix board name from nice_nano_v2 to nice_nano for ZMK build compatibility
2026-09-06 Fix keymap file format for device tree compilation
2026-09-06 Fix overlay to properly include keymap as device tree
